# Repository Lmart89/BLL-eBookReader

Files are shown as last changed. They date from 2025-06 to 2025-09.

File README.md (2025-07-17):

# 📘 Bll Pilot

**Bll Pilot** es un proyecto de hardware libre y software de código abierto cuyo propósito es crear un lector de eBooks bíblicos de bajo consumo, enfocado en la simplicidad, portabilidad y larga duración de batería, diseñado especialmente para funcionar en zonas de baja conectividad o para uso personal/devocional.

> ✝️ *“Bll” representa muchas cosas: por un lado, “Biblia de Lectura Libre”, como un enfoque hacia el acceso abierto a la Palabra. Pero también son las iniciales de tres personas que inspiran profundamente este proyecto: Brillyd (esposa), Lemuel (hijo) y Luis (autor). "Pilot" señala que esta es la primera etapa o base para versiones futuras.*

---

## 🚀 Estado del proyecto

✨ **Actualización clave:** Al adoptar el módulo Core 3506B, el proyecto gana notables ventajas:

- 🧠 Procesador Quad-Core para mejor rendimiento multitarea
- 🎨 GPU integrada que mejora la fluidez gráfica incluso en pantallas E-Ink
- 🚀 Duplicación de RAM: de 256MB (anteriormente) a 512MB DDR3L
- 🔌 Mayor cantidad de pines IO (120), facilitando expansión sin conflictos

Estas mejoras colocan al *Bll Pilot* en una posición robusta para futuras funcionalidades sin sacrificar simplicidad ni eficiencia.

🔧 En desarrollo activo – Actualmente se encuentra en fase de diseño de hardware y primeros prototipos físicos.

La primera versión se centrará en:
- Lectura offline de textos bíblicos
- Bajo consumo y pantalla de tinta electrónica
- Interfaz minimalista para navegación fluida

---

## 🔩 Características técnicas

### 🧠 Módulo principal

- **Módulo base:** `Luckfox Core 3506B`
- **Chip:** Rockchip RK3506B
- **Procesador:** 3× Cortex-A7 + 1× Cortex-M0
- **RAM:** 512 MB DDR3L externa
- **Almacenamiento:** eMMC 8 GB por defecto
- **Almacenamiento soportado:** SPI Flash / eMMC / SDMMC
- **RM_IO:** 32 pines Rockchip Matrix IO
- **GPU:** Aceleración 2D/3D integrada
- **Conectividad:** USB host, soporte para Wi-Fi vía dongle USB (o versión Lyra W con Wi-Fi onboard)
- **Dimensiones:** 32 mm × 32 mm
- **Conectores:** 120 pines tipo *stamp hole*

### 🖥️ Pantalla
- Tipo: Pantalla E-Ink ED060XD4 (6 pulgadas, reciclada de Kindle)
- Interfaz: SPI
- Controlador: Requiere PMIC externo (como TPS65185)

### 🔌 Conectividad
- Táctil capacitivo (opcional, vía I2C)
- MicroSD (opcional)
- USB tipo C para carga y datos

### 🔋 Energía
- Batería de polímero de litio (con circuito de protección y carga)
- Circuito de bajo consumo en standby

---

## 📱 Software

El sistema estará basado en:
- 🐧 **Linux embebido** con Buildroot
- 🧱 Interfaz ligera (basada en LVGL o framebuffer directo)
- 📖 Motor de renderizado de textos optimizado para pantallas E-Ink
- 🕮 Indexación de la Biblia en diferentes versiones
- ⛺ Posibilidad de agregar documentos EPUB, TXT o formatos ligeros

---

## 🔓 Licencia

### 🔧 Hardware
Este proyecto está licenciado bajo la **CERN Open Hardware License v2 – Strongly Reciprocal (CERN OHL v2-S)**.

> Esto significa que cualquier derivado del hardware deberá mantenerse igualmente abierto y compartido con la comunidad.

### 💾 Software
El software se publica bajo la **GNU General Public License v3.0 (GPLv3)**.

> Esta licencia protege las libertades de uso, estudio, modificación y distribución del código, asegurando que permanezca siempre libre para todos los usuarios.

---

## 🧭 Visión futura

**Bll Pilot** nace como una plataforma que va más allá de ser un lector de eBooks:

- 📖 Herramienta de estudio bíblico portátil
- ⛺ Recurso para comunidades en zonas rurales o de difícil acceso
- 🛠️ Plataforma educativa para makers que deseen aprender sobre hardware embebido
- 📚 Dispositivo de lectura privada o devocional

Más adelante podrían desarrollarse versiones ampliadas, con audio, conectividad Wi-Fi permanente, y sincronización de notas o planes de lectura.

---

## 🙏 Créditos y agradecimientos

Proyecto impulsado por Luis E. Martínez S., con pasión por la electrónica, la Biblia, y el aprendizaje autodidacta.

Inspirado en la necesidad de crear herramientas útiles, abiertas y accesibles para todos.

> *Soli Deo Gloria.*

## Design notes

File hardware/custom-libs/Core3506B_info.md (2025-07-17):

# 📦 Información técnica del módulo Luckfox Core 3506B

El **Luckfox Core 3506B** es un módulo de cómputo compacto basado en el chip **Rockchip RK3506B**, diseñado para aplicaciones embebidas que requieren buen rendimiento, eficiencia energética y flexibilidad de expansión. Es ideal para dispositivos portátiles como el lector *Bll Pilot*.

---

## 🔍 Especificaciones generales

| Campo | Descripción |
|---|---|
| **SoC** | Rockchip RK3506B |
| **CPU** | 3× ARM Cortex-A7 (hasta 1.5 GHz) + 1× Cortex-M0 |
| **GPU** | Integrada, soporte para gráficos 2D y 3D |
| **RAM** | 512 MB DDR3L externa |
| **Almacenamiento** | eMMC 8 GB integrada |
| **Soporte adicional** | SPI Flash, SDMMC (microSD) |
| **Pines RM_IO** | 32 líneas Rockchip Matrix IO |
| **Pines totales** | 120 pines tipo *stamp hole* (espaciado 2.54 mm) |
| **Interfaces disponibles**| SPI, I2C, UART, PWM, USB, GPIO, SDIO |
| **Dimensiones** | 32 mm × 32 mm |
| **Consumo energético** | Bajo (ideal para dispositivos portátiles) |
| **Conectividad** | USB Host, posibilidad de WiFi vía dongle USB<br>Versiones Lyra W integran WiFi onboard |

---

## ✅ Ventajas clave

- 🧠 **Rendimiento superior:** arquitectura de 4 núcleos (3 Cortex-A7 + 1 Cortex-M0)
- 🎨 **Aceleración gráfica:** GPU integrada con soporte para 2D/3D
- 🔄 **Matrix IO:** multiplexación flexible de 32 líneas IO
- 🔧 **Diseño compacto:** ideal para placas base personalizadas
- 🔌 **Expansión amplia:** gracias a sus 120 pines y variedad de interfaces
- 📦 **Módulo SOM:** con formato estándar y fácil integración en diseños embebidos

---

## 📁 Aplicaciones sugeridas

- 📘 Lectores de eBooks (como *Bll Pilot*)
- 🏭 Interfaces industriales simples
- 📟 Terminales embebidos con pantalla de bajo consumo
- 🌐 Dispositivos conectados con WiFi externo o controladores USB
- 🎓 Plataformas educativas y proyectos maker

---

## 📎 Notas adicionales

- El módulo requiere una placa base (carrier board) que lo alimente y exponga sus periféricos.
- No incluye Wi-Fi de fábrica en esta versión (Core 3506B), pero puede añadirse vía dongle USB o mediante el uso del modelo **Lyra W**.

---

> Para más detalles técnicos, puedes visitar: https://wiki.luckfox.com/Core3506/Introduction (sitio oficial del fabricante)

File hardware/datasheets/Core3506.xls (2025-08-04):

PIN | NAME | GPIO | RMIO | 0800 Domain | 0808 Domain | PINMUX
1 | GPO4_A4_z | 132 |  | 1.8V | 1.8V | MIPI_DPHY_DSI_TX_CLKN
2 | GPO4_A5_z | 133 |  | 1.8V | 1.8V | MIPI_DPHY_DSI_TX_CLKP
3 | GND
4 | GPO4_A2_z | 130 |  | 1.8V | 1.8V | MIPI_DPHY_DSI_TX_D1N
5 | GPO4_A3_z | 131 |  | 1.8V | 1.8V | MIPI_DPHY_DSI_TX_D1P
6 | GND
7 | GPO4_A0_z | 128 |  | 1.8V | 1.8V | MIPI_DPHY_DSI_TX_D0N
8 | GPO4_A1_z | 129 |  | 1.8V | 1.8V | MIPI_DPHY_DSI_TX_D0P
9 | GND
10 | GPIO2_C0_d | 80 |  | 3.3V | 3.3V | ETH_RMII0_RXDVCRS/SAI3_MCLK
11 | GPIO2_B7_d | 79 |  | 3.3V | 3.3V | ETH_RMII0_MDIO/DSM_AUD_LP_M1/SAI3_SDO
12 | GPIO2_B6_d | 78 |  | 3.3V | 3.3V | ETH_RMII0_MDC/DSM_AUD_LN_M1/SAI3_SDI
13 | GPIO2_B5_d | 77 |  | 3.3V | 3.3V | ETH_RMII0_TXEN/DSM_AUD_RP_M1/SAI3_LRCK
14 | GPIO2_B4_d | 76 |  | 3.3V | 3.3V | ETH_RMII0_TXD1/DSM_AUD_RN_M1/SAI3_SCLK
15 | GPIO2_B3_d | 75 |  | 3.3V | 3.3V | ETH_RMII0_TXD0/SPI2_MISO
16 | GPIO2_B2_d | 74 |  | 3.3V | 3.3V | ETH_RMII0_CLK/SPI2_MOSI
17 | GPIO2_B1_d | 73 |  | 3.3V | 3.3V | ETH_RMII0_RXD1/SPI2_CSN
18 | GPIO2_B0_d | 72 |  | 3.3V | 3.3V | ETH_RMII0_RXD0/SPI2_CLK
19 | GND
20 | GPIO2_A0_d | 64 |  | 3.3V | 3.3V | FSPI_CSN
21 | GPIO2_A1_d | 65 |  | 3.3V | 3.3V | FSPI_CLK
22 | GPIO2_A2_d | 66 |  | 3.3V | 3.3V | FSPI_D0
23 | GPIO2_A3_d | 67 |  | 3.3V | 3.3V | FSPI_D1
24 | GPIO2_A4_d | 68 |  | 3.3V | 3.3V | FSPI_D2
25 | GPIO2_A5_d | 69 |  | 3.3V | 3.3V | FSPI_D3
26 | GND
27 | GPIO1_D3_d | 59 | RM_IO31 | 3.3V | 3.3V | VO_LCDC_D0/DSMC_CSN3/FLEXBUS0_D0/UART5_RX_M1/RM_IO31/DSMC_SLV_RDYN
28 | GPIO1_D2_d | 58 | RM_IO30 | 3.3V | 3.3V | VO_LCDC_D1/DSMC_CSN2/FLEXBUS0_D1/UART5_TX_M1/RM_IO30/DSMC_SLV_CSN0
29 | GPIO1_D1_d | 57 | RM_IO29 | 3.3V | 3.3V | VO_LCDC_D2/DSMC_DQS1/FLEXBUS0_D2/DSM_AUD_LP_M0/UART5_RTSN_M1/RM_IO29/DSMC_SLV_D7
30 | GPIO1_D0_d | 56 |  | 3.3V | 3.3V | VO_LCDC_D3/DSMC_D15/FLEXBUS0_D3/DSM_AUD_LN_M0/DSMC_SLV_D6
31 | GPIO1_C7_d | 55 |  | 3.3V | 3.3V | VO_LCDC_D4/DSMC_D14/FLEXBUS0_D4/DSMC_SLV_D5
32 | GPIO1_C6_d | 54 |  | 3.3V | 3.3V | VO_LCDC_D5/DSMC_D13/FLEXBUS0_D5/DSMC_SLV_D4
33 | GPIO1_C5_d | 53 |  | 3.3V | 3.3V | VO_LCDC_D6/DSMC_D12/FLEXBUS0_D6/DSMC_SLV_D3
34 | GPIO1_C4_d | 52 |  | 3.3V | 3.3V | VO_LCDC_D7/DSMC_D11/FLEXBUS0_D7/DSMC_SLV_D2
35 | GPIO1_C3_d | 51 | RM_IO28 | 3.3V | 3.3V | VO_LCDC_D8/DSMC_D10/FLEXBUS0_D8/FLEXBUS1_CSN_M5/SAI2_SDO_M1/RM_IO28/DSMC_SLV_D1
36 | GPIO1_C2_d | 50 | RM_IO27 | 3.3V | 3.3V | VO_LCDC_D9/DSMC_D9/FLEXBUS0_D9/DSM_AUD_RP_M0/FLEXBUS0_CSN_M5/SAI2_SDI_M1/RM_IO27/DSMC_SLV_D0
37 | GPIO1_C1_d | 49 |  | 3.3V | 3.3V | VO_LCDC_D10/DSMC_D8/FLEXBUS0_CLK/DSM_AUD_RN_M0/FLEXBUS1_CSN_M4/SAI2_MCLK_M1/DSMC_SLV_DQS0
38 | GPIO1_C0_d | 48 |  | 3.3V | 3.3V | VO_LCDC_D11/DSMC_RESETN/FLEXBUS1_CLK/DSMC_INT1/FLEXBUS0_CSN_M4/DSMC_SLV_CLK
39 | GPIO1_B7_d | 47 |  | 3.3V | 3.3V | VO_LCDC_D12/DSMC_RDYN/FLEXBUS1_D15/FLEXBUS0_D10/FLEXBUS1_CSN_M3
40 | GPIO1_B6_d | 46 |  | 3.3V | 3.3V | VO_LCDC_D13/DSMC_CSN0/FLEXBUS1_D14/FLEXBUS0_D11/FLEXBUS0_CSN_M3
41 | GPIO1_B5_d | 45 |  | 3.3V | 3.3V | VO_LCDC_D14/DSMC_D7/FLEXBUS1_D13/FLEXBUS0_D12/FLEXBUS1_CSN_M2
42 | GPIO1_B4_d | 44 |  | 3.3V | 3.3V | VO_LCDC_D15/DSMC_D6/FLEXBUS1_D12/FLEXBUS0_D13/FLEXBUS0_CSN_M2
43 | GPIO1_B3_d | 43 | RM_IO26 | 3.3V | 3.3V | VO_LCDC_D16/DSMC_INT3/FLEXBUS1_D11/FLEXBUS0_D14/FLEXBUS1_CSN_M1/SAI2_LRCK_M1/RM_IO26
44 | GPIO1_B2_d | 42 | RM_IO25 | 3.3V | 3.3V | VO_LCDC_D17/DSMC_INT2/FLEXBUS1_D10/FLEXBUS0_D15/FLEXBUS0_CSN_M1/SAI2_SCLK_M1/RM_IO25
45 | GPIO1_B1_d | 41 | RM_IO24 | 3.3V | 3.3V | VO_LCDC_D18/DSMC_CSN1/FLEXBUS1_D9/FLEXBUS1_CSN_M0/UART5_CTSN_M1/RM_IO24
46 | GPIO1_B0_d | 40 |  |  |  | VO_LCDC_D19/DSMC_D5/FLEXBUS1_D8/FLEXBUS0_CSN_M0
47 | GND
48 | GPIO1_A7_d | 39 |  | 3.3V | 3.3V | VO_LCDC_D20/DSMC_D4/FLEXBUS1_D7
49 | GPIO1_A6_d | 38 |  | 3.3V | 3.3V | VO_LCDC_D21/DSMC_D3/FLEXBUS1_D6
50 | GPIO1_A5_d | 37 |  | 3.3V | 3.3V | VO_LCDC_D22/DSMC_D2/FLEXBUS1_D5
51 | GPIO1_A4_d | 36 |  | 3.3V | 3.3V | VO_LCDC_D23/DSMC_D1/FLEXBUS1_D4
52 | GPIO1_A3_d | 35 |  | 3.3V | 3.3V | VO_LCDC_CLK/DSMC_D0/FLEXBUS1_D3
53 | GPIO1_A2_d | 34 |  | 3.3V | 3.3V | VO_LCDC_HSYNC/DSMC_DQS0/FLEXBUS1_D2
54 | GPIO1_A1_d | 33 |  | 3.3V | 3.3V | VO_LCDC_VSYNC/DSMC_CLKN/FLEXBUS1_D1/DSMC_INT0/DSMC_SLV_INT
55 | GPIO1_A0_d | 32 |  | 3.3V | 3.3V | VO_LCDC_DEN/DSMC_CLKP/FLEXBUS1_D0
56 | GPIO0_C7_u | 23 | RMIO_23 | 3.3V | 3.3V | UART0_RX/JTAG_TMS_M1/RM_IO23
57 | GPIO0_C6_u | 22 | RMIO_22 | 3.3V | 3.3V | UART0_TX/JTAG_TCK_M1/RM_IO22
58 | GPIO0_C4_d | 20 | RMIO_20 | 3.3V | 3.3V | ETH_CLK0_25M_OUT/AUPLL_CLK_IN/RM_IO20
59 | GPIO0_C3_d | 19 | RMIO_19 | 3.3V | 3.3V | ETH_CLK1_25M_OUT/SPI0_CSN0/RM_IO19
60 | GPIO0_C2_d | 18 | RMIO_18 | 3.3V | 3.3V | REF_CLK1_OUT/SPI0_MISO/RM_IO18
61 | GPIO0_C1_d | 17 | RMIO_17 | 3.3V | 3.3V | SPI0_MOSI/RM_IO17
62 | GPIO0_C0_d | 16 | RMIO_16 | 3.3V | 3.3V | SPI0_CLK/RM_IO16
63 | GPIO0_B7_d | 15 | RMIO_15 | 3.3V | 3.3V | SAI1_SDO3/SPI0_CSN1/RM_IO15
64 | GPIO0_B6_d | 14 | RMIO_14 | 3.3V | 3.3V | SAI1_SDO2/SPI1_CSN0/RM_IO14
65 | GPIO0_B5_d | 13 | RMIO_13 | 3.3V | 3.3V | SAI1_SDO1/RM_IO13
66 | GPIO0_B4_d | 12 | RMIO_12 | 3.3V | 3.3V | SAI1_SDO0/RM_IO12
67 | GPIO0_B3_d | 11 | RMIO_11 | 3.3V | 3.3V | SAI1_SDI/RM_IO11
68 | GPIO0_B2_d | 10 | RMIO_10 | 3.3V | 3.3V | SAI1_LRCK/SPI1_MISO/RM_IO10
69 | GPIO0_B1_d | 9 | RMIO_9 | 3.3V | 3.3V | SAI1_SCLK/SPI1_MOSI/RM_IO9
70 | GPIO0_B0_d | 8 | RMIO_8 | 3.3V | 3.3V | SAI1_MCLK/SPI1_CLK/RM_IO8
71 | GND
72 | GPIO0_A7_d | 7 | RMIO_7 | 3.3V | 3.3V | SAI0_SDI3/SPI1_CSN1/RM_IO7
73 | GPIO0_A6_d | 6 | RMIO_6 | 3.3V | 3.3V | SAI0_SDI2/RM_IO6
74 | GPIO0_A5_d | 5 | RMIO_5 | 3.3V | 3.3V | SAI0_SDI1/RM_IO5
75 | GPIO0_A4_d | 4 | RMIO_4 | 3.3V | 3.3V | SAI0_SDI0/RM_IO4
76 | GPIO0_A3_d | 3 | RMIO_3 | 3.3V | 3.3V | SAI0_SDO/RM_IO3
77 | GPIO0_A2_u | 2 | RMIO_2 | 3.3V | 3.3V | SAI0_MCLK/RM_IO2
78 | GPIO0_A1_d | 1 | RMIO_1 | 3.3V | 3.3V | SAI0_SCLK/RM_IO1
79 | GPIO0_A0_u | 0 | RMIO_0 | 3.3V | 3.3V | SAI0_LRCK/RM_IO0
80 | NPOR_L |  |  | 3.3V | 3.3V
81 | GND
82 | GPIO0_D0_d | 24 |  | 3.3V | 3.3V | OSC_CLK_OUT/REF_CLK0_OUT
83 | VCC_1V8
84 | VCC_3V3
85 | VCC5V0_SYS
86 | VCC5V0_SYS
87 | VCC5V0_SYS
88 | GND
89 | GND
90 | GND
91 | GPIO3_B6_d | 110 |  | 3.3V | 1.8V | SAI2_MCLK_M0/ETH_RMII1_RXDVCRS
92 | GPIO3_B5_d | 109 |  | 3.3V | 1.8V | UART5_RTSN_M0/ETH_RMII1_MDIO
93 | GPIO3_B4_d | 108 |  | 3.3V | 1.8V | UART5_TX_M0/ETH_RMII1_MDC
94 | GPIO3_B3_d | 107 |  | 3.3V | 1.8V | UART5_RX_M0/ETH_RMII1_TXEN
95 | GPIO3_B2_d | 106 |  | 3.3V | 1.8V | UART5_CTSN_M0/ETH_RMII1_TXD1
96 | GPIO3_B1_d | 105 |  | 3.3V | 1.8V | SAI2_LRCK_M0/ETH_RMII1_TXD0
97 | GPIO3_B0_d | 104 |  | 3.3V | 1.8V | SAI2_SDO_M0/ETH_RMII1_CLK
98 | GPIO3_A7_d | 103 |  | 3.3V | 1.8V | SAI2_SCLK_M0/ETH_RMII1_RXD1
99 | GPIO3_A6_d | 102 |  | 3.3V | 1.8V | SAI2_SDI_M0/ETH_RMII1_RXD0
100 | GND
101 | GPIO3_A5_d | 101 |  | 3.3V | 1.8V(NC) | SDMMC_D3/JTAG_TMS_M0
102 | GPIO3_A4_d | 100 |  | 3.3V | 1.8V(NC) | SDMMC_D2/JTAG_TCK_M0
103 | GPIO3_A3_d | 99 |  | 3.3V | 1.8V(NC) | SDMMC_D1/TEST_CLK_OUT
104 | GPIO3_A2_d | 98 |  | 3.3V | 1.8V(NC) | SDMMC_D0
105 | GPIO3_A1_d | 97 |  | 3.3V | 1.8V(NC) | SDMMC_CMD
106 | GPIO3_A0_d | 96 |  | 3.3V | 1.8V(NC) | SDMMC_CLK
107 | GND
108 | USB20_OTG0_D_P
109 | USB20_OTG0_D_N
110 | USB20_OTG1_D_P
111 | USB20_OTG1_D_N
112 | USB20_OTG0_ID
113 | USB20_OTG0_VBUSDET
114 | GPIO4_B0_z | 136 |  | 1.8V | 1.8V | SARADC_IN0
115 | GPIO4_B1_z | 137 |  | 1.8V | 1.8V | SARADC_IN1
116 | GPIO4_B2_z | 138 |  | 1.8V | 1.8V | SARADC_IN2
117 | GPIO4_B3_z | 139 |  | 1.8V | 1.8V | SARADC_IN3
118 | GND
119 | ACODEC_ADC_IN_P |  |  | 1.8V | 1.8V
120 | ACODEC_ADC_IN_N |  |  | 1.8V | 1.8V

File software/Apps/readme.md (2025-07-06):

# 📖 eBook Reader - Apps y Módulos

Este documento describe las **aplicaciones** que forman parte del eBook Reader, los lenguajes utilizados, sus dependencias, cómo integrarlas al sistema y ejemplos prácticos de desarrollo.

---

## 🛠 Lenguajes y frameworks

Las aplicaciones del eBook Reader están desarrolladas principalmente en:

| Componente | Lenguaje | Framework |
|---|---|---|
| Interfaz gráfica | C / C++  | LVGL (Light and Versatile Graphics Library) |
| Lógica / Backend | C / C++  | Nativo, sin frameworks pesados |
| Scripts utilitarios | Python (opcional, durante generación de datos, no en runtime) | - |

El uso de C/C++ permite máxima eficiencia en el hardware limitado (RV1106, 256 MB RAM).

### ⚙ Herramientas de compilación sugeridas

- **Makefiles** o **CMake** para proyectos C/C++.
- Toolchain generada por Buildroot (cross-compilador para RV1106).
- LVGL como librería estática incluida en el build.

---

## 📦 Aplicaciones principales

| App | Descripción | Binario / Módulo | Dependencias |
|---|---|---|---|
| **BibleTool** | Lectura, búsqueda y estudio bíblico | Binario integrado  | LVGL, acceso a CSV/JSON |
| **BookReader**| Lector de libros electrónicos | Binario integrado  | LVGL |
| **NoteApp** | App de notas y apuntes | Módulo o binario | LVGL |
| **Settings**  | Configuración del sistema | Módulo esencial | LVGL |

---

## 🔗 Integración al eBook Reader

- **Formato**: Las apps se integran como binarios independientes o módulos que el sistema llama desde el menú principal.
- **Compilación**: Cada app debe ser compilada estáticamente o como binario cargable desde el almacenamiento.
- **Recursos compartidos**: Framebuffer, entrada táctil (si disponible), eMMC, red.
- **Datos**: Formatos planos (CSV, JSON) alojados en el eMMC.

### 📂 Ejemplo de estructura de proyecto

```
/apps
  /bibletool
    main.c
    Makefile
    lv_conf.h
    /assets
      logo.bin
    /data
      rv60.csv
      diccionario.json
```

### 📝 Ejemplo de Makefile

```makefile
CC = arm-linux-gnueabihf-gcc
CFLAGS = -O2 -static
LDFLAGS = -llvgl

TARGET = bibletool
SRCS = main.c

all:
\t$(CC) $(CFLAGS) -o $(TARGET) $(SRCS) $(LDFLAGS)

clean:
\trm -f $(TARGET)
```

### 🚀 Comando de compilación

```bash
make
```
o manualmente:
```bash
arm-linux-gnueabihf-gcc -O2 -static -o bibletool main.c -llvgl
```

### 🛠 Instrucciones para integrar el binario

1️⃣ Copia el binario al dispositivo:
```bash
scp bibletool root@device:/apps/bibletool
```

2️⃣ Asegura permisos de ejecución:
```bash
chmod +x /apps/bibletool
```

3️⃣ Edita el menú del launcher:
```bash
vi /etc/ebook_launcher.conf
```
Y añade:
```
BibleTool,/apps/bibletool
```

---

## ✅ Requerimientos para añadir nuevas apps

- C/C++ o compatible con el entorno minimalista.
- Uso de LVGL o interfaz directa sobre framebuffer.
- Binarios compactos (ideal < 2 MB).
- Sin librerías externas pesadas.
- Integración al menú mediante launcher.

---

## 📄 Licencia

Las aplicaciones están licenciadas bajo **GPLv3**, salvo indicación diferente en casos particulares.

---

Si deseas más detalles sobre la creación de nuevas aplicaciones o la arquitectura de integración, revisa la documentación de **Buildroot** y **LVGL**.

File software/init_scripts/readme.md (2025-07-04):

# Scripts

Aqui se encuentran los scripts de configuracion del sistema buildroot. 
y cualquier otro script de configuracion o inicializacion de alguno de los componentes
o configuracion del software o scripts de inicializacion de paquetes personalizados.

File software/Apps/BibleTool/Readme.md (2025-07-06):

# BibleTool

**BibleTool** es una aplicación ligera, eficiente y de bajo consumo diseñada para el estudio y la consulta de la Biblia en dispositivos de recursos limitados, como e-readers basados en Linux con Buildroot (por ejemplo: el eReader personalizado de este proyecto).

BibleTool se construye con el objetivo de ofrecer una experiencia de estudio bíblico fluida, práctica y personalizable, sin sacrificar velocidad ni simplicidad.

---

## ¿Qué es BibleTool?

BibleTool es un motor de lectura y búsqueda bíblica que:

- Permite consultar el texto completo de la Biblia en español (Reina-Valera 1960 o 1909).
- Realiza búsquedas rápidas de palabras o frases en toda la Biblia, por testamento o por tipo de libro (ley, histórico, poético, profético, evangelio, epístola, apocalíptico).
- Muestra comentarios asociados a versículos específicos.
- Permite consultar definiciones y conceptos mediante un diccionario bíblico integrado.
- Diseñado para una interfaz basada en **LVGL** (Light and Versatile Graphics Library) y código en **C/C++**.

---

## Funcionalidades principales

✅ **Consulta de versículos**\
✅ **Búsqueda avanzada por palabra clave** (con filtros: testamento, tipo de libro)\
✅ **Acceso a comentarios vinculados al texto bíblico**\
✅ **Consulta de diccionario bíblico**\
✅ **Soporte para módulos adicionales (comentarios, diccionarios)**\
✅ **Bajo consumo de recursos (256 MB RAM, CPU RV1106)**\
✅ **Datos optimizados en archivos CSV y JSON**

---

## Arquitectura de módulos

BibleTool está organizado en módulos que corresponden a distintos tipos de contenido:

| Módulo | Descripción | Tipo de archivo | Formato |
| --- | --- | --- | --- |
| **Biblia** | Texto completo de las Escrituras | CSV | Lb,C,V,TXT,TP,Tlb |
| **Comentarios** | Notas y comentarios por versículo o pasaje | JSON | Lista de objetos con referencia al libro, capítulo, versículo |
| **Diccionario** | Definiciones de términos bíblicos | JSON o CSV | Clave: término / Valor: definición |

### 📁 Formato de la Biblia (CSV)

| Columna | Descripción |
| --- | --- |
| Lb | Nombre del libro |
| C | Capítulo (entero positivo) |
| V | Versículo (entero positivo) |
| TXT | Texto del versículo |
| TP | Testamento: `A` = Antiguo, `N` = Nuevo |
| Tlb | Tipo de libro: `L`, `H`, `P`, `Pm`, `Pn`, `E`, `Ep`, `Ap` |

Ejemplo:

```csv
Genesis,1,1,"En el principio creó Dios los cielos y la tierra.",A,L
Mateo,1,1,"Libro de la genealogía de Jesucristo, hijo de David, hijo de Abraham.",N,E
```

---

### 📁 Formato de los comentarios (JSON)

```json
[
  {
    "Lb": "Genesis",
    "C": 1,
    "V": 1,
    "Comentario": "Dios es el creador de todo lo visible e invisible."
  },
  {
    "Lb": "Mateo",
    "C": 1,
    "V": 1,
    "Comentario": "Introducción a la genealogía de Cristo."
  }
]
```

---

### 📁 Formato del diccionario (JSON)

```json
{
  "Amor": "Sentimiento de afecto y entrega desinteresada.",
  "Fe": "Confianza y creencia en Dios y sus promesas."
}
```

*(También puede usarse CSV con dos columnas: Término, Definición)*

---

## ¿Por qué BibleTool es útil y versátil?

- 🔹 **Ligero y rápido:** Diseñado para funcionar con hardware de bajo consumo (como RV1106 + 256MB RAM).
- 🔹 **Modular:** Puedes agregar o actualizar los módulos (Biblia, comentarios, diccionarios) sin modificar el motor.
- 🔹 **Filtros de búsqueda avanzados:** Busca por testamento, tipo de libro, o combinación de ambos.
- 🔹 **Fácil de adaptar:** El formato de datos es simple, plano y bien documentado.
- 🔹 **Libre de dependencias innecesarias:** Motor hecho en C/C++ con una interfaz LVGL optimizada.

---

## Licencia

BibleTool es un proyecto abierto en desarrollo. Licencia GPLv3

---

## Créditos

BibleTool es desarrollado por **Luis E Martínez S.** como parte de un proyecto personal de eReader personalizado para estudio bíblico.

---

*Nota:* En el futuro se podrá definir un logo y otros elementos visuales para BibleTool.

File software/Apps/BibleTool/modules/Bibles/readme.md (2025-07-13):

## 📚 Progreso del Módulo de la Biblia (RV60)

Este módulo representa el corazón textual de **BibleTool**, centrado en una fuente depurada y confiable de la Biblia Reina Valera 1960 (RV60).  
A continuación se presenta el registro de validaciones y avances técnicos hasta la fecha:

---

### 🛠️ Etapas de Validación Aplicadas

| Etapa | Descripción | Estado |
|---|---|---|
| ✅ Estructura CSV definida | Archivo `rv60.csv` con columnas: `Lb`, `C`, `V`, `TXT`, `TP`, `Tlb` | Completado |
| ✅ Verificación de formato | Validación de campos no vacíos, orden y consistencia por versículo | Completado |
| ✅ Chequeo de integridad bíblica  | Revisión de libros, capítulos y versículos conforme a la RV60 | Completado |
| 🧪 Comparación textual | Comparación verso a verso contra RV1909 por conteo de palabras | En curso  |
| 🧠 Revisión semántica manual | Evaluación del significado y conservación del mensaje bíblico | En curso  |
| 🧩 Filtrado de sospechosos | Identificación de versículos con diferencias mayores al 50% | Completado |
| 🗂️ Exclusión de libros validados | Script conectado a archivo `libros_verificados.py` | Implementado |

---

### ✅ Libros Verificados (RV60 vs RV1909)

| 📖 Libro | Estado | Observación |
|---|---|---|
| Génesis | ✅ Verificado | Cambios menores de estilo sin alterar el contenido |
| Éxodo | ✅ Verificado | Diferencias lingüísticas no afectan integridad doctrinal |
| Levítico  | ⏳ En proceso | - |
| ... | | |

> Los libros verificados son excluidos automáticamente en futuras ejecuciones del comparador textual.

---

### 🧰 Herramientas de validación usadas

- `BibleChecker` – Validación de capítulos y versículos
- `comparador_rv60_rv1909.py` – Comparación textual palabra por palabra
- `libros_verificados.py` – Control automático de libros revisados
- Archivos de referencia: `SpaRV.csv` (RV1909), `rv60.csv` (RV60 final)

---

### 🔜 Próximos pasos

- 📗 Verificar Levítico y Números
- 📂 Consolidar lista de libros verificados
- ✏️ Implementar vista de lectura en LVGL
- 📦 Empaquetar recursos optimizados para el eReader

---

_Actualizado: **{{FECHA_HOY}}** por Luis E. Martínez (con asistencia de Chatty 🤖)_

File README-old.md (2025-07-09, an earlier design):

# 📖 Bll eBook Reader

**Un lector electrónico versátil, eficiente y con propósito**

---

## ✨ ¿Qué es el Bll eBook Reader?

El **Bll eBook Reader** es un lector de libros electrónicos creado desde cero, pensado no solo como una alternativa a dispositivos comerciales como el Kindle, sino como una **herramienta versátil de lectura, estudio y organización personal**, especialmente útil para quienes estudian, enseñan o predican la Biblia. Diseñado para funcionar con recursos limitados, es **libre, optimizado y altamente personalizable**.

---

## 🔧 Hardware

Este lector se basa en un hardware distinto a la mayoría de dispositivos similares, lo que permite libertad total en su desarrollo y expansión:

- **Procesador**: Luckfox Core RV1106 – Cortex-A7, eficiente y de bajo consumo.
- **RAM**: 256 MB DDR3
- **Almacenamiento**: 8 GB eMMC (integrado)
- **Pantalla**: E-Ink de 6 pulgadas (sin retroiluminación por ahora)
- **Touch**: Opcional, no habilitado en las primeras versiones
- **Conectividad**: Wi-Fi / Bluetooth integrados
- **Sistema Operativo**: Linux personalizado usando **Buildroot**
- **Placa Base**: Diseño propio (inspirado en proyectos como epdiy v7 pero adaptado al RV1106)
- **Fuente de alimentación y protección**: Incluye fusibles para proteger el SoM

---

## 🚀 Características destacadas

- 🧠 **Ultraligero**: sistema operativo minimalista con lo esencial, optimizado para bajo uso de RAM y energía.
- 📚 **Soporte para múltiples formatos de eBooks**: EPUB, MOBI, TXT, PDF (parcial).
- 📖 **Modo Biblia integrado**: navegación optimizada por libros, capítulos y versículos.
- 📝 **Notas personales**: sistema simple de notas para estudios, bosquejos y predicaciones.
- 📡 **Actualizaciones inalámbricas** (por Wi-Fi).
- 📁 **Sistema de archivos organizado** para acceder a libros, notas y documentos con rapidez.

---

## 🎯 ¿Por qué es diferente?

La mayoría de lectores electrónicos están cerrados a modificaciones. El **Bll eBook Reader** es:

- ✅ **Totalmente libre y abierto**: el software está bajo licencia GPLv3 y el hardware bajo una licencia de hardware libre.
- ✅ **Protegido contra la apropiación comercial restrictiva**: cualquier persona que modifique o redistribuya debe mantener la apertura del código y los archivos de hardware.
- ✅ **Versátil**: no se limita a libros; puede convertirse en una libreta digital, lector de notas pastorales, organizador de predicaciones, etc.
- ✅ **Diseñado para crecer**: puede extenderse con mejoras como pantalla táctil, retroiluminación o integración con servidores locales para compartir materiales.

---

## 🧱 Estado del desarrollo

- [x] Diseño del PCB personalizado
- [x] Integración básica con pantalla E-Ink
- [x] Sistema Linux embebido funcional (Buildroot)
- [ ] Interfaz gráfica liviana con **LVGL**
- [ ] Modo Biblia con navegación completa
- [ ] Sistema de notas sencillo
- [ ] Conectividad Wi-Fi funcional y segura
- [ ] Soporte para sincronización o backup

---

## 💡 Casos de uso

- Lectura diaria de la Biblia y devocionales
- Acceso a libros de estudio teológico
- Organización de bosquejos para sermones
- Anotaciones rápidas durante clases o reuniones
- Lectura offline de contenido útil sin distracciones

---

## 📜 Licencia

### Software

Este proyecto se distribuye bajo los términos de la **GNU General Public License v3.0 (GPLv3)**.  
Esto garantiza que cualquier persona que modifique o redistribuya el software **debe mantenerlo libre y accesible** bajo la misma licencia.

Consulta el archivo [`LICENSE`](./LICENSE) para más información.

### Hardware

Los archivos de hardware (esquemáticos, PCB, listas de materiales) se publican como **Open Hardware** bajo la licencia  
**CERN Open Hardware License v2 – Strongly Reciprocal**.  
Esto significa que:

- Puedes usar, estudiar, modificar y fabricar este hardware.
- Si lo redistribuyes o haces productos derivados, **debes también liberar tus archivos bajo la misma licencia**.
- **No está permitido cerrarlo ni venderlo como producto propietario** sin publicar tus modificaciones.

Consulta el archivo [`hardware/LICENSE`](./hardware/LICENSE) para más información.

---

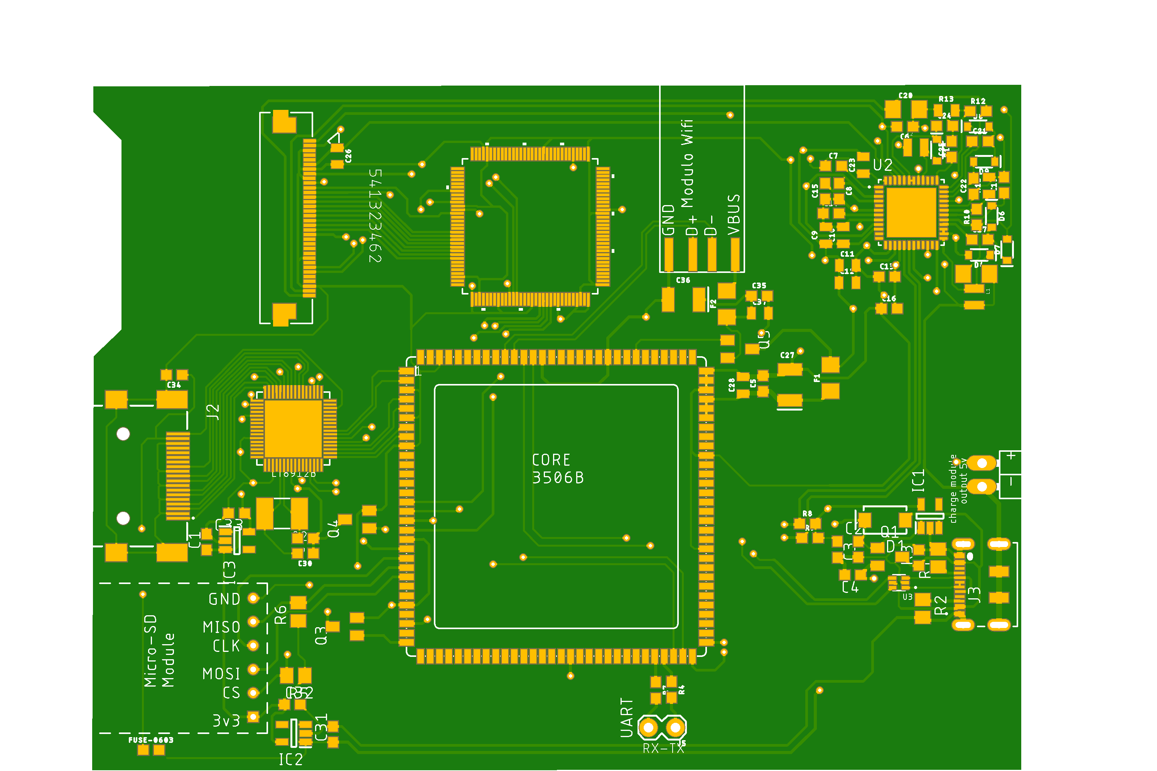
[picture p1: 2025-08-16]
hardware/sch-pcb files/BLL-EBOOK-3506-TOP.png

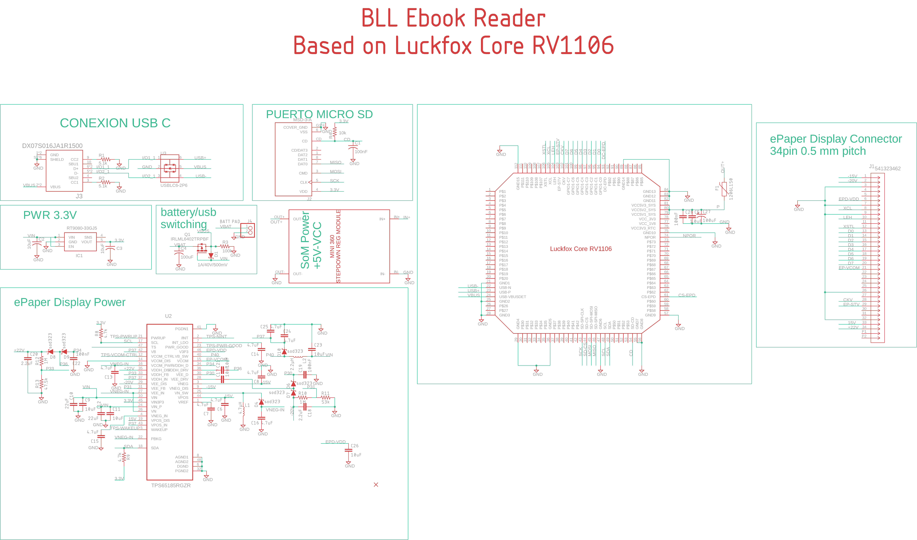
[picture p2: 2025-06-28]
hardware/sch-pcb files/SCH_V1.png

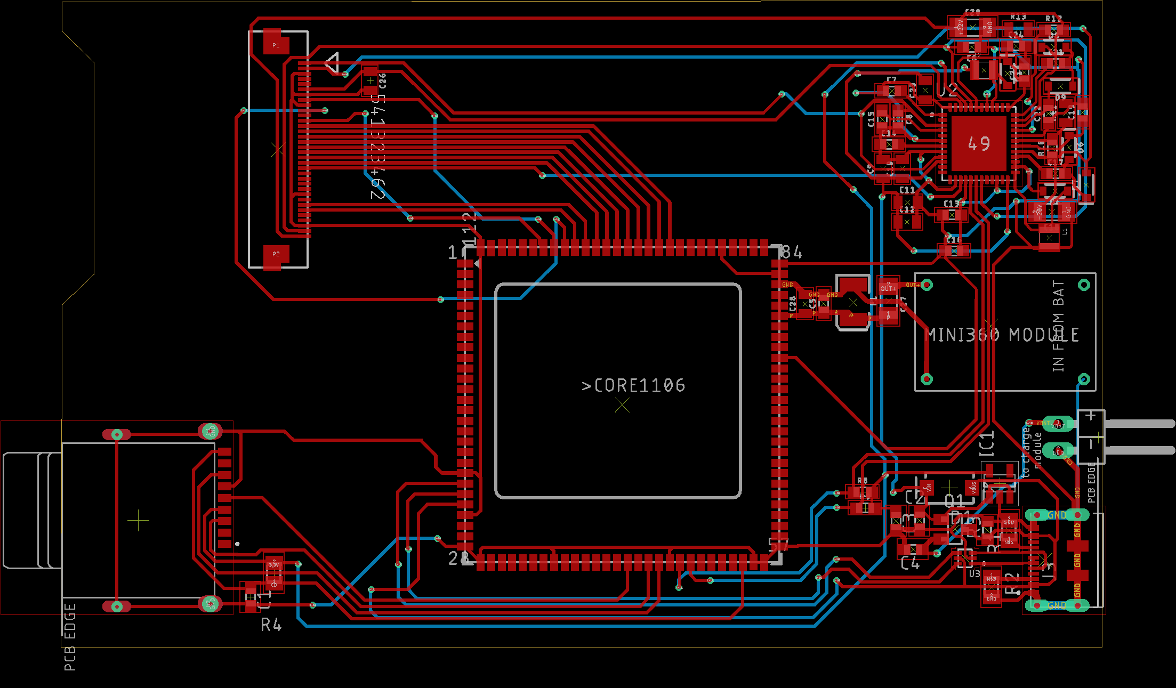
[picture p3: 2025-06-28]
hardware/sch-pcb files/PCB.png

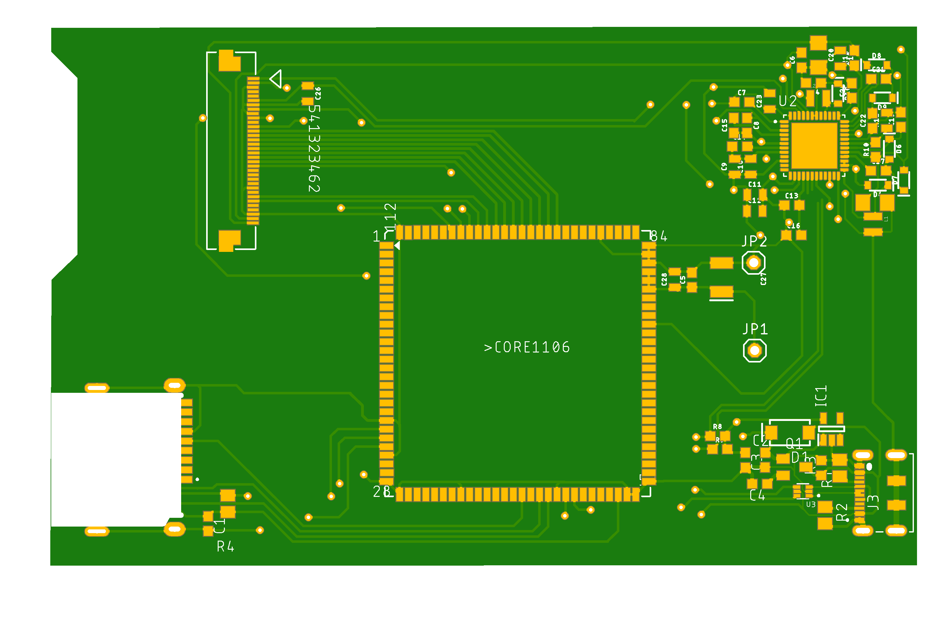
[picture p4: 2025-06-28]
docs/img/BLL-EBOOK - TOP.png

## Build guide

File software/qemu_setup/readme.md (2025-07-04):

# Qemu - Setup

esta carpeta contiene los scripts y/o opciones de configuracion de qemu para la virtualizacion, emulacion
del Buildroot en el sistema.

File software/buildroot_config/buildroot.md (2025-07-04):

# Buildroot Config

Aqui se encontrara la documentacion para la creacion de una imagen de Linux Buildroot,
y pueda ser grabada al emmc de la Bll eBook Reader.

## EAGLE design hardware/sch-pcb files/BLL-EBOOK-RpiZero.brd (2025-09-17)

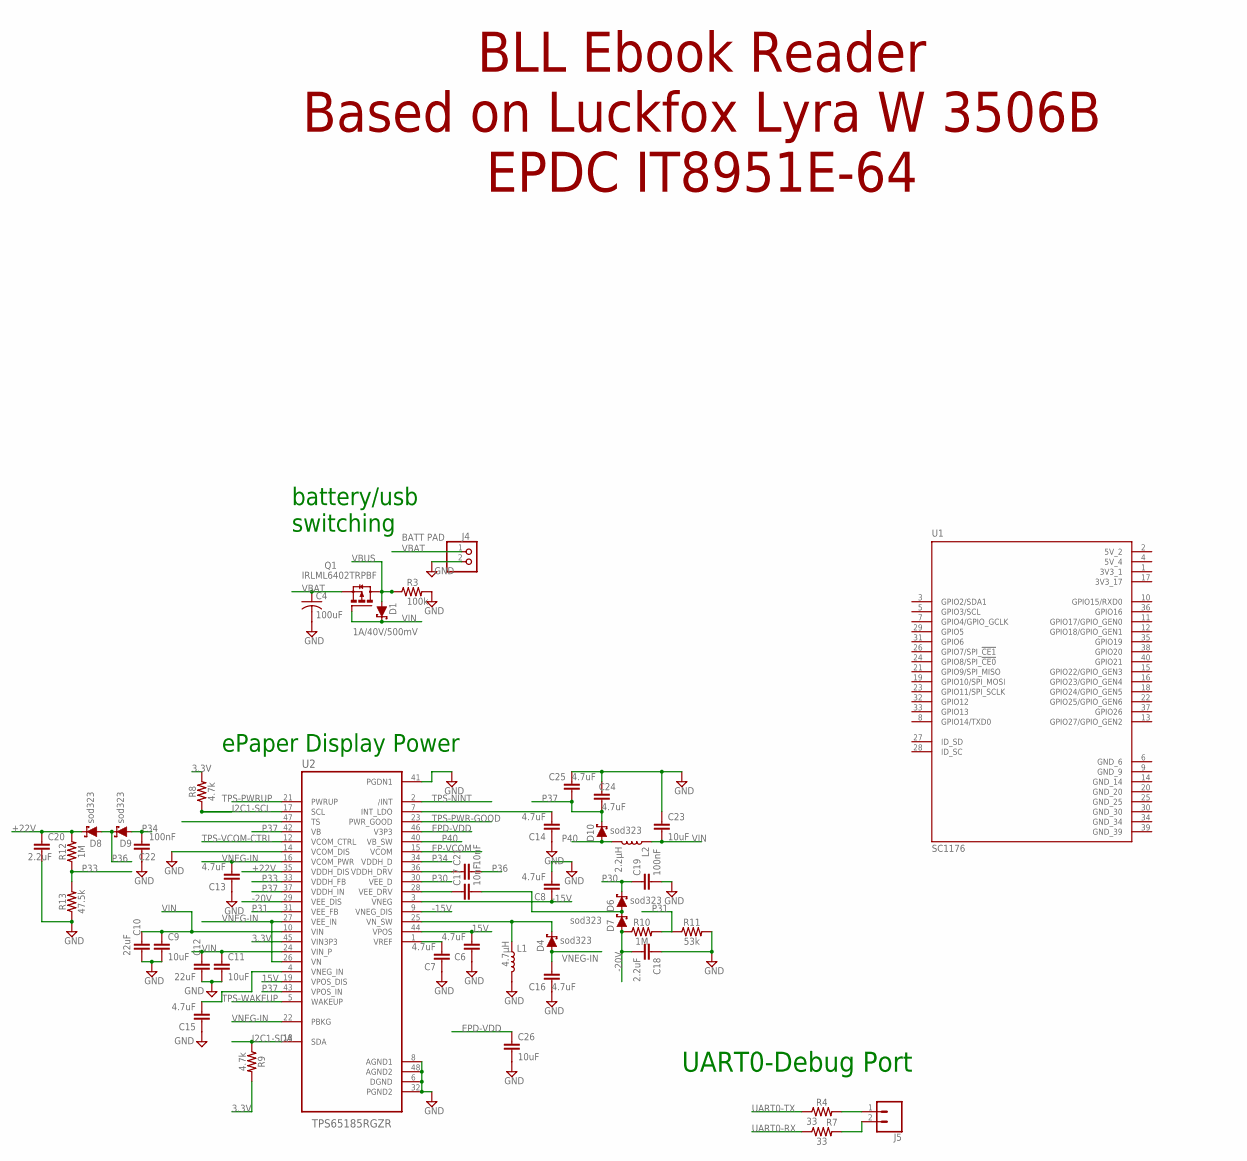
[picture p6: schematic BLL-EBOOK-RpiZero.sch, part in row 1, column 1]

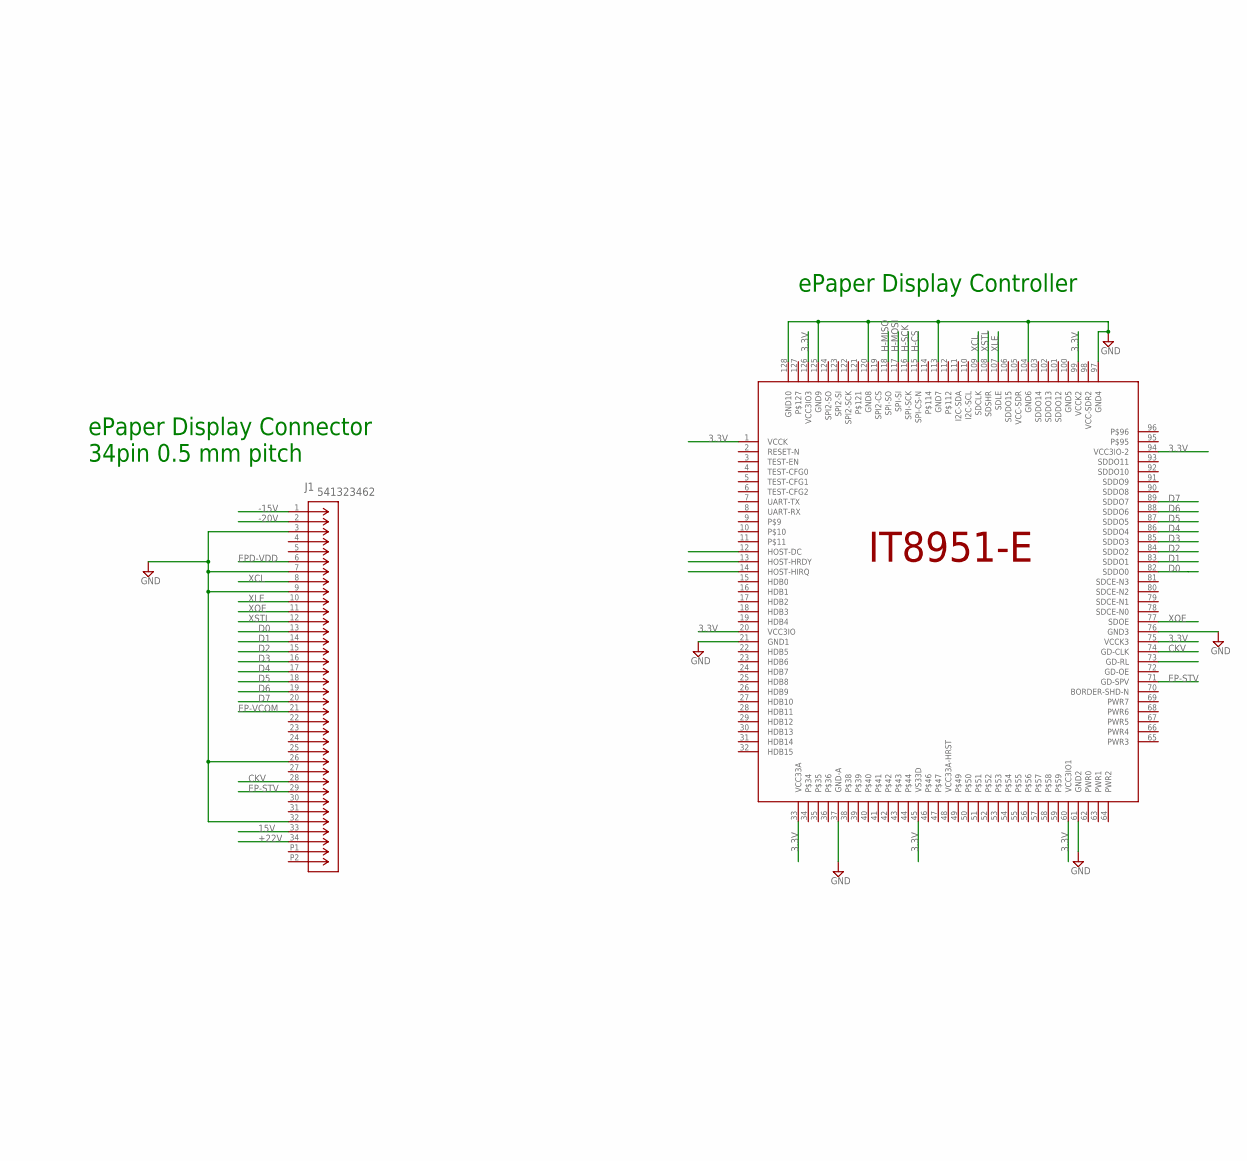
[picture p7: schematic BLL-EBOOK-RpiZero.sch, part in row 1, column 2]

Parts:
C4: 100uF; C0603
C6, C7, C8, C13, C14, C15, C16, C24, C25: 4.7uF; 0603
C9, C11, C23, C26: 10uF; 0805
C10, C12: 22uF; 0805
C17, C21: 10nF; 0603
C18, C20: 2.2uF; 1206
C19, C22: 100nF; 0603
D1: 1A/40V/500mV; SMA-DIODE
D4, D6, D7, D8, D9, D10: sod323; SOD-323
J1: 541323462; CON_541323462_MOL
J4: BATT PAD; 1X02/90
J5: CONN_02LOCK; 1X02_LOCK
L1: 4.7μH; 1008(2520)
L2: 2.2μH; 0806
Q1: IRLML6402TRPBF; SOT23
R3: 100k; R0603
R4, R7: 33; 0603
R8, R9: 4.7k; 0603
R10, R12: 1M; 0603
R11: 53k; 0805
R13: 47.5k; 0805
U1: SC1176; MODULE_SC1176
U2: TPS65185RGZR; QFN50P700X700X100-49N
U$1: IT8951; LQFP128_STM

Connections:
3.3V: R8.2, R9.2, U2.45 (VIN3P3), U$1.1 (VCCK), U$1.20 (VCC3IO), U$1.33 (VCC33A), U$1.45 (VS33D), U$1.60 (VCC3IO1), U$1.75 (VCCK3), U$1.94 (VCC3IO-2), U$1.99 (VCCK2), U$1.126 (VCC3IO3)
3V3_1: U1.1 (3V3_1)
3V3_17: U1.17 (3V3_17)
5V_2: U1.2 (5V_2)
5V_4: U1.4 (5V_4)
15V: C6.2, J1.33, U2.19 (VPOS_DIS), U2.44 (VPOS)
+22V: C20.1, D8.C, J1.34, R12.2, U2.35 (VDDH_DIS)
-15V: C8.1, J1.1, U2.3 (VNEG), U2.9 (VNEG_DIS)
-20V: C18.2, D7.A, J1.2, R10.1, U2.29 (VEE_DIS)
CKV: J1.28, U$1.74 (GD-CLK)
D0: J1.13, U$1.82 (SDDO0)
D1: J1.14, U$1.83 (SDDO1)
D2: J1.15, U$1.84 (SDDO2)
D3: J1.16, U$1.85 (SDDO3)
D4: J1.17, U$1.86 (SDDO4)
D5: J1.18, U$1.87 (SDDO5)
D6: J1.19, U$1.88 (SDDO6)
D7: J1.20, U$1.89 (SDDO7)
EP-STV: J1.29, U$1.71 (GD-SPV)
EP-VCOM: J1.21, U2.15 (VCOM)
EPD-VDD: C26.1, J1.6, U2.46 (V3P3)
GND: C4.2, C6.1, C7.1, C8.2, C9.2, C10.2, C11.2, C12.2, C13.1, C14.1, C15.1, C16.1, C18.1, C19.2, C20.2, C22.1, C23.1, C24.2, C25.2, C26.2, J1.3, J1.7, J1.9, J1.26, J1.32, J4.2, L1.2, R3.2, R11.2, R13.1, U2.6 (DGND), U2.8 (AGND1), U2.14 (VCOM_DIS), U2.32 (PGND2), U2.41 (PGDN1), U2.48 (AGND2), U$1.21 (GND1), U$1.37 (GND-A), U$1.61 (GND2), U$1.76 (GND3), U$1.97 (GND4), U$1.104 (GND6), U$1.113 (GND7), U$1.120 (GND8), U$1.125 (GND9), U$1.128 (GND10)
GND_6: U1.6 (GND_6)
GND_9: U1.9 (GND_9)
GND_14: U1.14 (GND_14)
GND_20: U1.20 (GND_20)
GND_25: U1.25 (GND_25)
GND_30: U1.30 (GND_30)
GND_34: U1.34 (GND_34)
GND_39: U1.39 (GND_39)
H-CS: U$1.115 (SPI-CS-N)
H-MISO: U$1.118 (SPI-SO)
H-MOSI: U$1.117 (SPI-SI)
H-SCK: U$1.116 (SPI-SCK)
I2C1-SCL: R8.1, U2.17 (SCL)
I2C1-SDA: R9.1, U2.18 (SDA)
unnamed: J5.1, R4.2
unnamed: J5.2, R7.2
unnamed: C7.2, U2.1 (VREF)
unnamed: C15.2, U2.4 (VNEG_IN)
unnamed: C14.2, U2.7 (INT_LDO)
unnamed: D4.C, L1.1, U2.25 (VN_SW)
unnamed: C17.1, U2.28 (VEE_DRV)
unnamed: C17.2, D6.A, D7.C
unnamed: C21.1, U2.36 (VDDH_DRV)
P30: C19.1, D6.C, U2.30 (VEE_D)
P31: R10.2, R11.1, U2.31 (VEE_FB)
P33: R12.1, R13.2, U2.33 (VDDH_FB)
P34: C22.2, D9.A, U2.34 (VDDH_D)
P36: C21.2, D8.A, D9.C
P37: C24.1, C25.1, D10.C, U2.37 (VDDH_IN), U2.42 (VB), U2.43 (VPOS_IN)
P40: D10.A, L2.2, U2.40 (VB_SW)
TPS-NINT: U2.2 (/INT)
TPS-PWR-GOOD: U2.23 (PWR_GOOD)
TPS-PWRUP: U2.21 (PWRUP)
TPS-VCOM-CTRL: U2.12 (VCOM_CTRL)
TPS-WAKEUP: U2.5 (WAKEUP)
UART0-RX: R7.1
UART0-TX: R4.1
VBAT: C4.1, J4.1, Q1.2 (S)
VBUS: D1.A, Q1.3 (D), R3.1
VIN: C9.1, C10.1, C11.1, C12.1, C23.2, D1.C, L2.1, Q1.1 (G), U2.10 (VIN), U2.24 (VIN_P)
VNEG-IN: C13.2, C16.2, D4.A, U2.16 (VCOM_PWR), U2.22 (PBKG), U2.26 (VN), U2.27 (VEE_IN)
XCL: J1.8, U$1.109 (SDCLK)
XLE: J1.10, U$1.107 (SDLE)
XOE: J1.11, U$1.77 (SDOE)
XSTL: J1.12, U$1.108 (SDSHR)

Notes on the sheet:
battery/usb switching
ePaper Display Power
ePaper Display Connector 34pin 0.5 mm pitch
BLL Ebook Reader Based on Luckfox Lyra W 3506B EPDC IT8951E-64
ePaper Display Controller
UART0-Debug Port

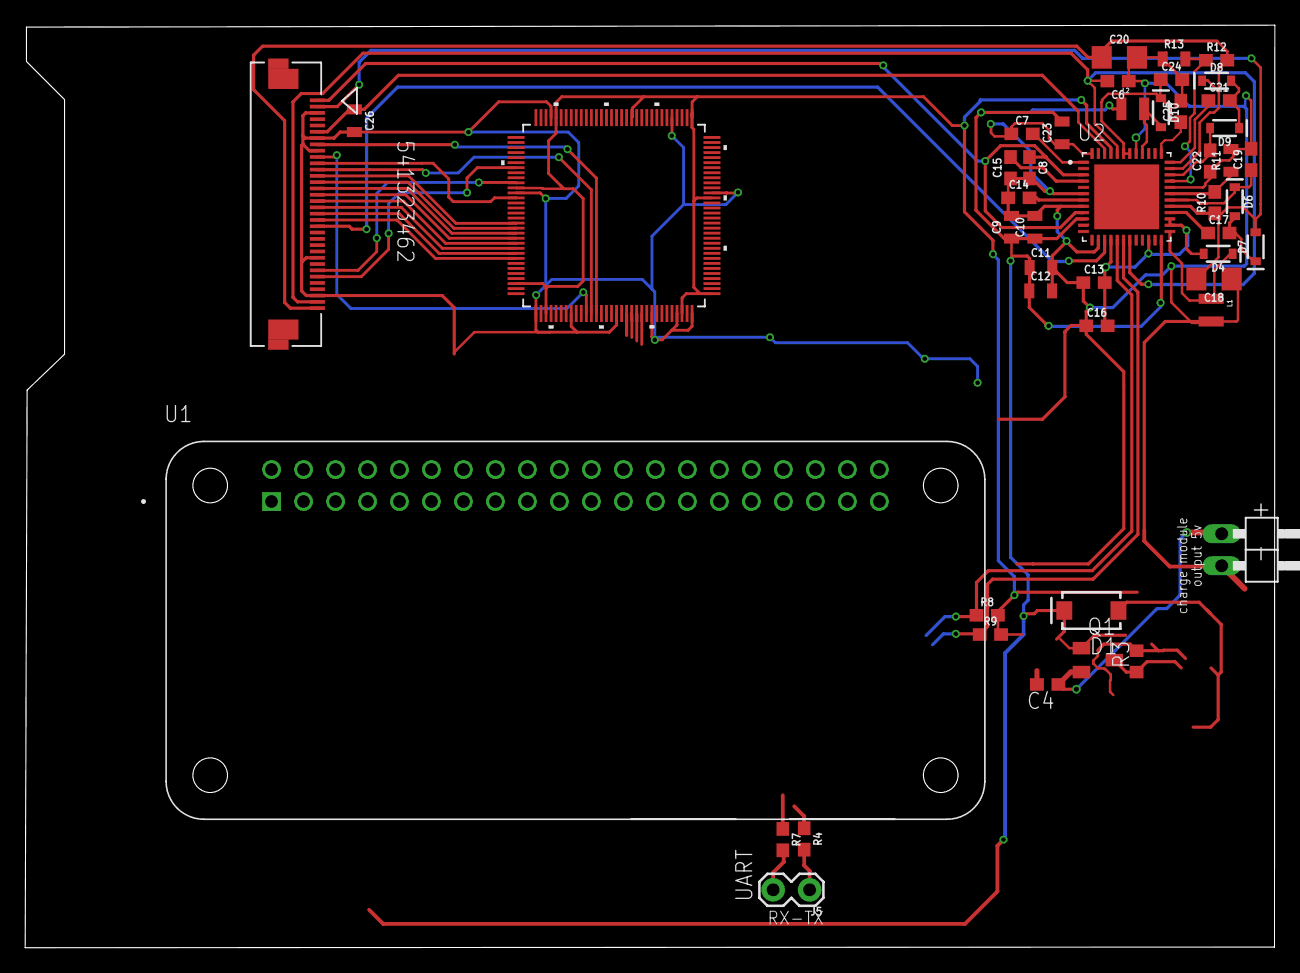
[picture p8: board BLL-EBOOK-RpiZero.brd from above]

Board: 2 copper layers, 99.2 x 73.2 mm, 47 parts (0 on the bottom side), 44 nets.

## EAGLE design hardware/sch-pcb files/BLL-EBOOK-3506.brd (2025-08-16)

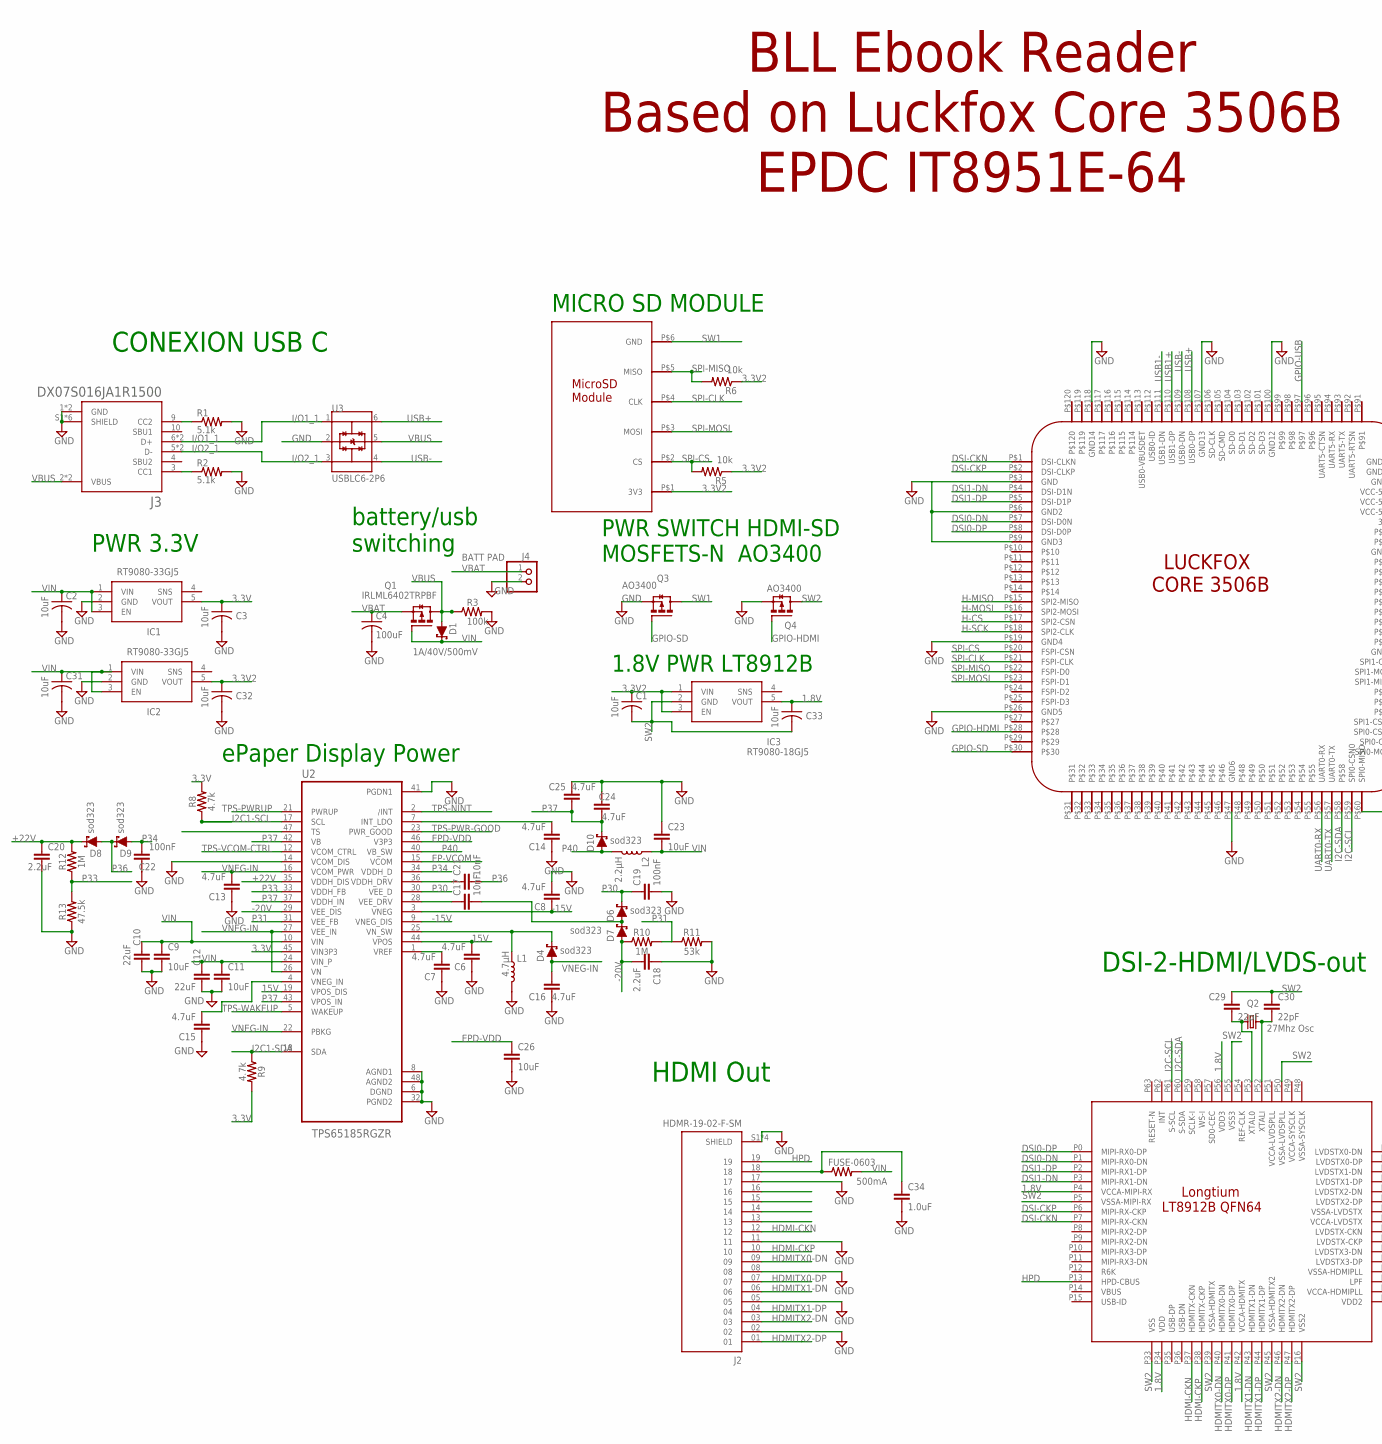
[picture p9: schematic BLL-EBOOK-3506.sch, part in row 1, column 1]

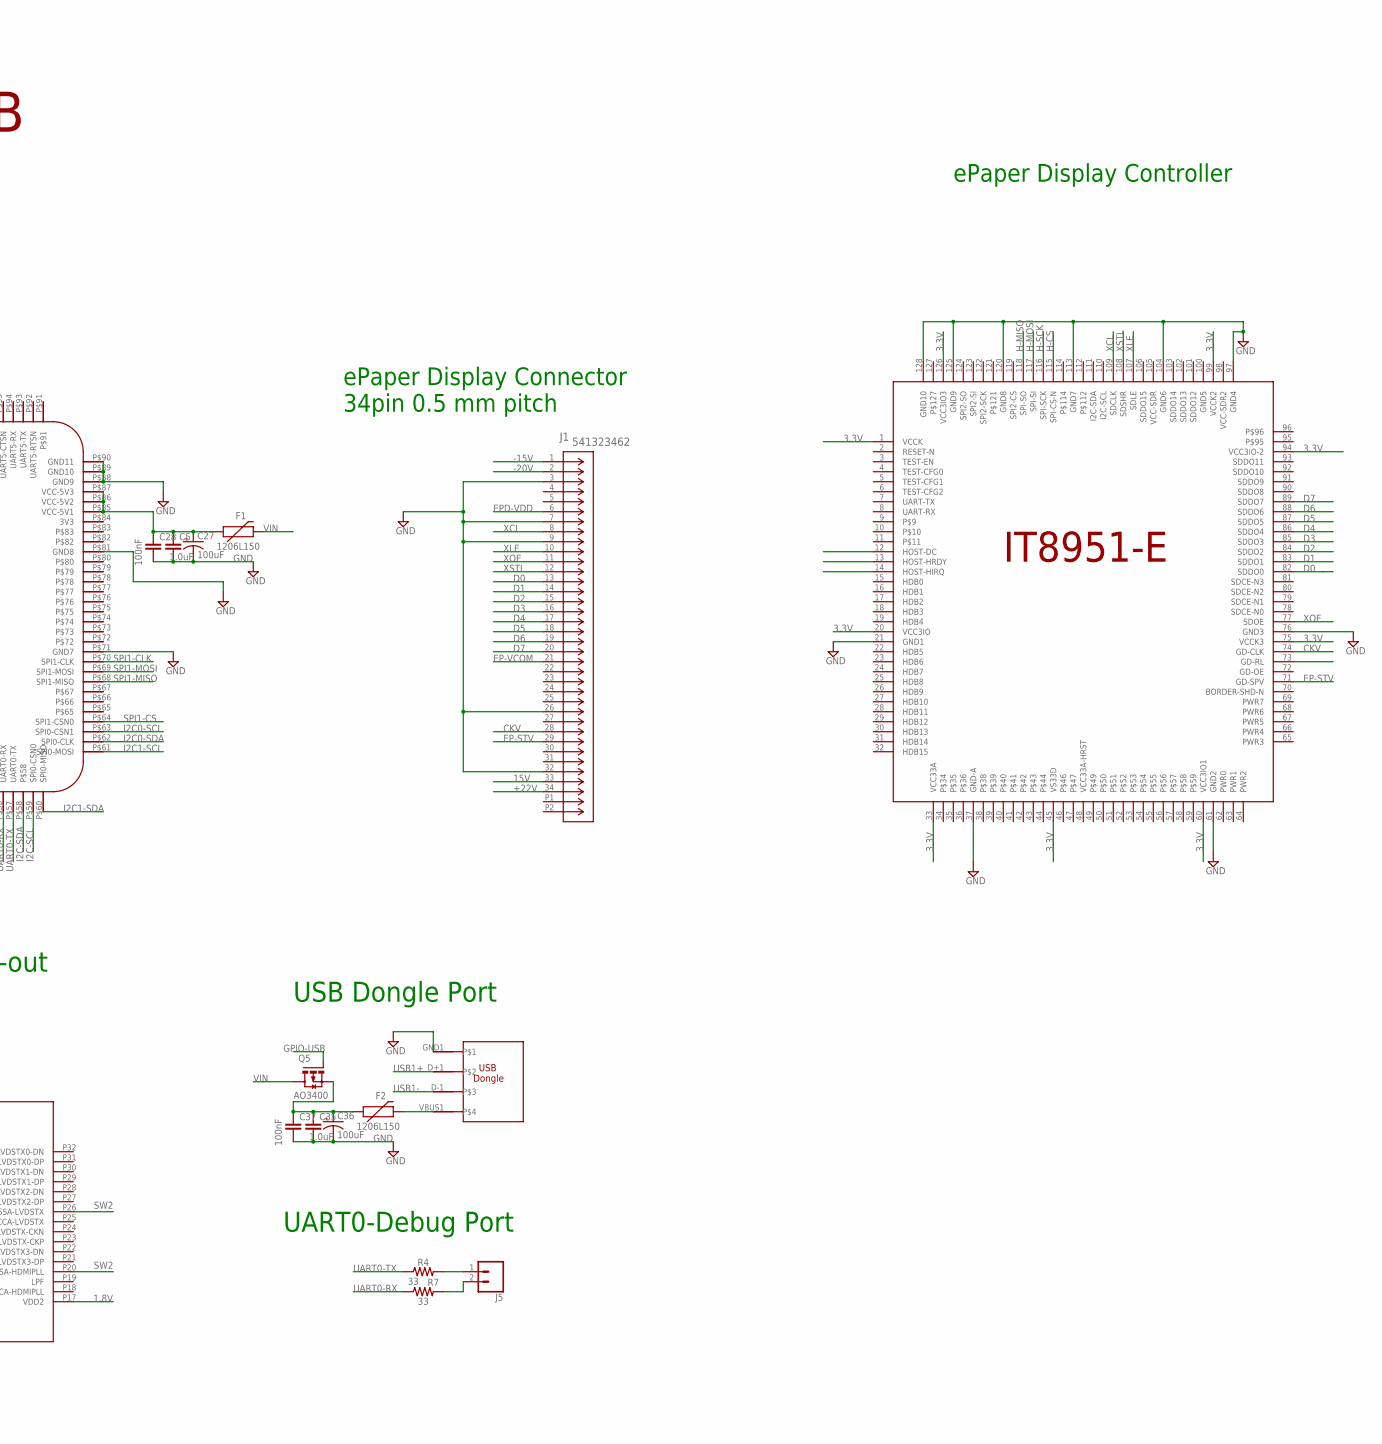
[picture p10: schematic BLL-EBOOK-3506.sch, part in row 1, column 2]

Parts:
C1, C2, C3, C31, C32, C33: 10uF; C0603
C4: 100uF; C0603
C5, C34, C35: 1.0uF; 0603
C6, C7, C8, C13, C14, C15, C16, C24, C25: 4.7uF; 0603
C9, C11, C23, C26: 10uF; 0805
C10, C12: 22uF; 0805
C17, C21: 10nF; 0603
C18, C20: 2.2uF; 1206
C19, C22: 100nF; 0603
C27, C36: 100uF; EIA3528
C28, C37: 100nF; 0805
C29, C30: 22pF; 0603
D1: 1A/40V/500mV; SMA-DIODE
D4, D6, D7, D8, D9, D10: sod323; SOD-323
F1, F2: 1206L150; 1206
FUSE-0603: 500mA; 0603
IC1, IC2: RT9080-33GJ5; SOT94P280X100-5N
IC3: RT9080-18GJ5; SOT94P280X100-5N
J1: 541323462; CON_541323462_MOL
J2: HDMR-19-02-F-SM; SAMTEC_HDMR-19-02-F-SM
J3: DX07S016JA1R1500; JAE_DX07S016JA1R1500
J4: BATT PAD; 1X02/90
J5: CONN_02LOCK; 1X02_LOCK
L1: 4.7μH; 1008(2520)
L2: 2.2μH; 0806
LT8912: LT8912B
Q1: IRLML6402TRPBF; SOT23
Q2: 27Mhz Osc; 5.0X3.2_2
Q3, Q4, Q5: AO3400; SOT23
R1, R2: 5.1k; M0805
R3: 100k; R0603
R4, R7: 33; 0603
R5, R6: 10k; M0805
R8, R9: 4.7k; 0603
R10, R12: 1M; 0603
R11: 53k; 0805
R13: 47.5k; 0805
U2: TPS65185RGZR; QFN50P700X700X100-49N
U3: USBLC6-2P6; SOT50P160X60-6N
U$1: IT8951; LQFP128_STM
U$3: LUCKFOX_CORE3506; CORE3506
U$4: MICROSD-MODULE; MICROSD-MOD
U$5: USB-WIFI-DONGLE; USB-A-SMT-MALE

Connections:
1.8V: C33.1, IC3.5 (VOUT), LT8912.P4 (VCCA-MIPI-RX), LT8912.P17 (VDD2), LT8912.P34 (VDD), LT8912.P42 (VCCA-HDMITX), LT8912.P56 (VDD3)
3.3V: C3.1, IC1.5 (VOUT), R8.2, R9.2, U2.45 (VIN3P3), U$1.1 (VCCK), U$1.20 (VCC3IO), U$1.33 (VCC33A), U$1.45 (VS33D), U$1.60 (VCC3IO1), U$1.75 (VCCK3), U$1.94 (VCC3IO-2), U$1.99 (VCCK2), U$1.126 (VCC3IO3)
3.3V2: C1.1, C32.1, IC2.5 (VOUT), IC3.1 (VIN), IC3.3 (EN), R5.1, R6.1, U$4.P$1 (3V3)
15V: C6.2, J1.33, U2.19 (VPOS_DIS), U2.44 (VPOS)
+22V: C20.1, D8.C, J1.34, R12.2, U2.35 (VDDH_DIS)
-15V: C8.1, J1.1, U2.3 (VNEG), U2.9 (VNEG_DIS)
-20V: C18.2, D7.A, J1.2, R10.1, U2.29 (VEE_DIS)
CKV: J1.28, U$1.74 (GD-CLK)
D0: J1.13, U$1.82 (SDDO0)
D1: J1.14, U$1.83 (SDDO1)
D2: J1.15, U$1.84 (SDDO2)
D3: J1.16, U$1.85 (SDDO3)
D4: J1.17, U$1.86 (SDDO4)
D5: J1.18, U$1.87 (SDDO5)
D6: J1.19, U$1.88 (SDDO6)
D7: J1.20, U$1.89 (SDDO7)
DSI0-DN: LT8912.P1 (MIPI-RX0-DN), U$3.P$7 (DSI-D0N)
DSI0-DP: LT8912.P0 (MIPI-RX0-DP), U$3.P$8 (DSI-D0P)
DSI1-DN: LT8912.P3 (MIPI-RX1-DN), U$3.P$4 (DSI-D1N)
DSI1-DP: LT8912.P2 (MIPI-RX1-DP), U$3.P$5 (DSI-D1P)
DSI-CKN: LT8912.P7 (MIPI-RX-CKN), U$3.P$1 (DSI-CLKN)
DSI-CKP: LT8912.P6 (MIPI-RX-CKP), U$3.P$2 (DSI-CLKP)
EP-STV: J1.29, U$1.71 (GD-SPV)
EP-VCOM: J1.21, U2.15 (VCOM)
EPD-VDD: C26.1, J1.6, U2.46 (V3P3)
GND: C2.2, C3.2, C4.2, C5.2, C6.1, C7.1, C8.2, C9.2, C10.2, C11.2, C12.2, C13.1, C14.1, C15.1, C16.1, C18.1, C19.2, C20.2, C22.1, C23.1, C24.2, C25.2, C26.2, C27.C (-), C28.2, C31.2, C32.2, C34.2, C35.2, C36.C (-), C37.2, IC1.2 (GND), IC2.2 (GND), J1.3, J1.7, J1.9, J1.26, J1.32, J2.02, J2.05, J2.08, J2.11, J2.17, J2.S1 (SHIELD), J2.S2 (SHIELD), J2.S3 (SHIELD), J2.S4 (SHIELD), J3.1 (GND), J3.12 (GND), J3.S1 (SHIELD), J3.S2 (SHIELD), J3.S3 (SHIELD), J3.S4 (SHIELD), J3.S5 (SHIELD), J3.S6 (SHIELD), J4.2, L1.2, Q3.2 (S), Q4.2 (S), R1.2, R2.2, R3.2, R11.2, R13.1, U2.6 (DGND), U2.8 (AGND1), U2.14 (VCOM_DIS), U2.32 (PGND2), U2.41 (PGDN1), U2.48 (AGND2), U3.2 (GND), U$1.21 (GND1), U$1.37 (GND-A), U$1.61 (GND2), U$1.76 (GND3), U$1.97 (GND4), U$1.104 (GND6), U$1.113 (GND7), U$1.120 (GND8), U$1.125 (GND9), U$1.128 (GND10), U$3.P$3 (GND), U$3.P$6 (GND2), U$3.P$9 (GND3), U$3.P$19 (GND4), U$3.P$26 (GND5), U$3.P$47 (GND6), U$3.P$71 (GND7), U$3.P$81 (GND8), U$3.P$88 (GND9), U$3.P$89 (GND10), U$3.P$90 (GND11), U$3.P$100 (GND12), U$3.P$107 (GND13), U$3.P$118 (GND14), U$5.GND1
GPIO-HDMI: Q4.1 (G), U$3.P$28
GPIO-SD: Q3.1 (G), U$3.P$30
GPIO-USB: Q5.1 (G), U$3.P$97
H-CS: U$1.115 (SPI-CS-N), U$3.P$17 (SPI2-CSN)
H-MISO: U$1.118 (SPI-SO), U$3.P$15 (SPI2-MISO)
H-MOSI: U$1.117 (SPI-SI), U$3.P$16 (SPI2-MOSI)
H-SCK: U$1.116 (SPI-SCK), U$3.P$18 (SPI2-CLK)
HDMI-CKN: J2.12, LT8912.P37 (HDMITX-CKN)
HDMI-CKP: J2.10, LT8912.P38 (HDMITX-CKP)
HDMITX0-DN: J2.09, LT8912.P40 (HDMITX0-DN)
HDMITX0-DP: J2.07, LT8912.P41 (HDMITX0-DP)
HDMITX1-DN: J2.06, LT8912.P43 (HDMITX1-DN)
HDMITX1-DP: J2.04, LT8912.P44 (HDMITX1-DP)
HDMITX2-DN: J2.03, LT8912.P46 (HDMITX2-DN)
HDMITX2-DP: J2.01, LT8912.P47 (HDMITX2-DP)
HPD: J2.19, LT8912.P13 (HPD-CBUS)
I2C0-SCL: U$3.P$63 (SPI0-CSN1)
I2C0-SDA: U$3.P$62 (SPI0-CLK)
I2C1-SCL: R8.1, U2.17 (SCL), U$3.P$61 (SPI0-MOSI)
I2C1-SDA: R9.1, U2.18 (SDA), U$3.P$60 (SPI0-MISO)
I2C-SCL: LT8912.P61 (S-SCL), U$3.P$59 (SPI0-CSN0)
I2C-SDA: LT8912.P60 (S-SDA), U$3.P$58
I/O1_1: J3.6 (D+), J3.7 (D+), U3.1 (I/O1_1)
I/O2_1: J3.5 (D-), J3.8 (D-), U3.3 (I/O2_1)
unnamed: C29.2, LT8912.P53 (XTAL0), Q2.1
unnamed: C30.2, LT8912.P52 (XTALI), Q2.2
unnamed: J3.3 (CC1), R2.1
unnamed: J3.9 (CC2), R1.1
unnamed: F2.2, U$5.VBUS1
unnamed: J5.1, R4.2
unnamed: J5.2, R7.2
unnamed: C7.2, U2.1 (VREF)
unnamed: C15.2, U2.4 (VNEG_IN)
unnamed: C14.2, U2.7 (INT_LDO)
unnamed: D4.C, L1.1, U2.25 (VN_SW)
unnamed: C17.1, U2.28 (VEE_DRV)
unnamed: C17.2, D6.A, D7.C
unnamed: C21.1, U2.36 (VDDH_DRV)
unnamed: C34.1, FUSE-0603.1, J2.18
P: C5.1, C27.A (+), C28.1, F1.1, U$3.P$85 (VCC-5V1), U$3.P$86 (VCC-5V2), U$3.P$87 (VCC-5V3)
P1: C35.1, C36.A (+), C37.1, F2.1, Q5.2 (S)
P30: C19.1, D6.C, U2.30 (VEE_D)
P31: R10.2, R11.1, U2.31 (VEE_FB)
P33: R12.1, R13.2, U2.33 (VDDH_FB)
P34: C22.2, D9.A, U2.34 (VDDH_D)
P36: C21.2, D8.A, D9.C
P37: C24.1, C25.1, D10.C, U2.37 (VDDH_IN), U2.42 (VB), U2.43 (VPOS_IN)
P40: D10.A, L2.2, U2.40 (VB_SW)
SPI1-CLK: U$3.P$70 (SPI1-CLK)
SPI1-CS: U$3.P$64 (SPI1-CSN0)
SPI1-MISO: U$3.P$68 (SPI1-MISO)
SPI1-MOSI: U$3.P$69 (SPI1-MOSI)
SPI-CLK: U$3.P$21 (FSPI-CLK), U$4.P$4 (CLK)
SPI-CS: R5.2, U$3.P$20 (FSPI-CSN), U$4.P$2 (CS)
SPI-MISO: R6.2, U$3.P$22 (FSPI-D0), U$4.P$5 (MISO)
SPI-MOSI: U$3.P$23 (FSPI-D1), U$4.P$3 (MOSI)
SW1: Q3.3 (D), U$4.P$6 (GND)
SW2: C1.2, C29.1, C30.1, C33.2, IC3.2 (GND), LT8912.P5 (VSSA-MIPI-RX), LT8912.P16 (VSS2), LT8912.P20 (VSSA-HDMIPLL), LT8912.P26 (VSSA-LVDSTX), LT8912.P33 (VSS), LT8912.P39 (VSSA-HDMITX), LT8912.P45 (VSSA-HDMITX2), LT8912.P50 (VSSA-LVDSPLL), LT8912.P55 (VSS3), Q4.3 (D)
TPS-NINT: U2.2 (/INT)
TPS-PWR-GOOD: U2.23 (PWR_GOOD)
TPS-PWRUP: U2.21 (PWRUP)
TPS-VCOM-CTRL: U2.12 (VCOM_CTRL)
TPS-WAKEUP: U2.5 (WAKEUP)
UART0-RX: R7.1, U$3.P$56 (UART0-RX)
UART0-TX: R4.1, U$3.P$57 (UART0-TX)
USB1+: U$3.P$110 (USB1-DP), U$5.D+1
USB1-: U$3.P$111 (USB1-DN), U$5.D-1
USB+: U3.6 (I/O1_2), U$3.P$108 (USB0-DP)
USB-: U3.4 (I/O2_2), U$3.P$109 (USB0-DN)
VBAT: C4.1, J4.1, Q1.2 (S)
VBUS: D1.A, J3.2 (VBUS), J3.11 (VBUS), Q1.3 (D), R3.1, U3.5 (VBUS)
VIN: C2.1, C9.1, C10.1, C11.1, C12.1, C23.2, C31.1, D1.C, F1.2, FUSE-0603.2, IC1.1 (VIN), IC1.3 (EN), IC2.1 (VIN), IC2.3 (EN), L2.1, Q1.1 (G), Q5.3 (D), U2.10 (VIN), U2.24 (VIN_P)
VNEG-IN: C13.2, C16.2, D4.A, U2.16 (VCOM_PWR), U2.22 (PBKG), U2.26 (VN), U2.27 (VEE_IN)
XCL: J1.8, U$1.109 (SDCLK)
XLE: J1.10, U$1.107 (SDLE)
XOE: J1.11, U$1.77 (SDOE)
XSTL: J1.12, U$1.108 (SDSHR)

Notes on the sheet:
CONEXION USB C
MICRO SD MODULE
PWR 3.3V
battery/usb switching
ePaper Display Power
ePaper Display Connector 34pin 0.5 mm pitch
BLL Ebook Reader Based on Luckfox Core 3506B EPDC IT8951E-64
ePaper Display Controller
DSI-2-HDMI/LVDS-out
PWR SWITCH HDMI-SD MOSFETS-N AO3400
1.8V PWR LT8912B
HDMI Out
USB Dongle Port
UART0-Debug Port

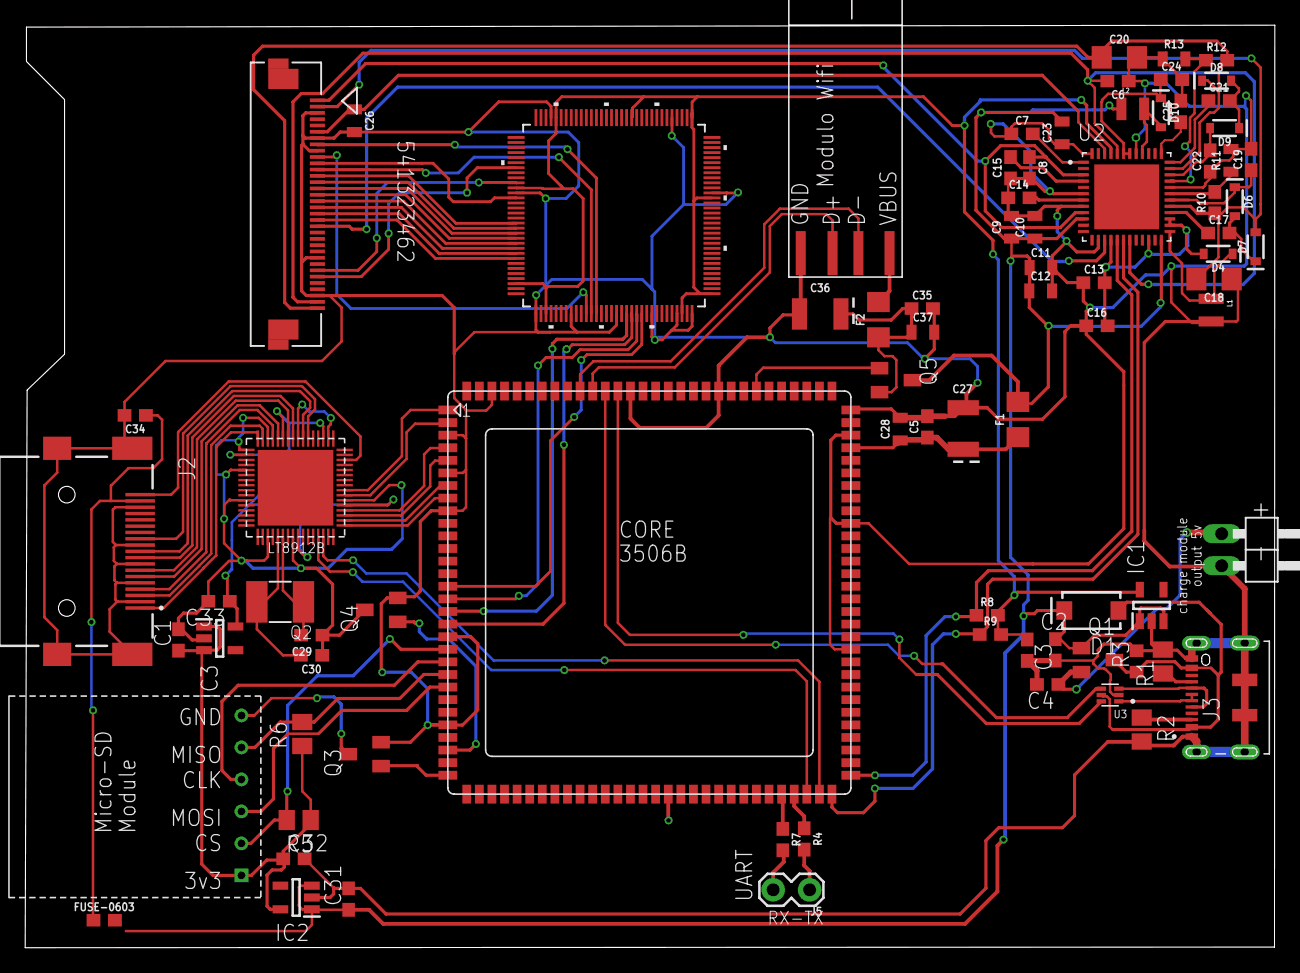
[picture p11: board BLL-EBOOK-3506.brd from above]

Board: 2 copper layers, 99.2 x 73.2 mm, 82 parts (0 on the bottom side), 92 nets.

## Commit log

2025-06-28 UPDATE FILES
    ADD PCB FILES AND EAGLE CUSTOM LIBS
    [BLL-EBOOK.brd, BLL-EBOOK.sch]
2025-06-28 new pcb and sch files
    [BLL-EBOOK.brd, BLL-EBOOK.sch]
2025-06-30 reorganized of repository structure
    [BLL-EBOOK.brd, BLL-EBOOK.sch]
2025-07-04 new bible module
    [rv60 - copia.csv, rv60.csv]
2025-07-05 update rv60 bible text
    [rv60.csv]
2025-07-06 Bibletool updated readme and bible modules
    [rv60.csv]
2025-07-06 instructions for developing and compiling apps
    [rv60.csv]
2025-07-08 complete version of RV60 Bible and tools for validation of files
    [rv60-prueba.csv, rv60.csv]
2025-07-13 Update readme.md
    Bible de log for documentation
2025-07-13 last version of rv60.csv with new text corrections
    deleted duplicated verses, and fixed some verses leng untill Exodus book.
    still need some fixes that will be available as soon as possible.
    - added spanish rv1909 bible (rv09) as a trusted source for local comparison of verses and checking integrity of rv60 spanish bible. also available as a bible version.
    [rv60-prueba.csv]
2025-07-17 new platform build
    [BLL-EBOOK-3506B.brd, BLL-EBOOK-3506B.sch]
2025-07-27 new core design for bll pilot
    [BLL-EBOOK-3506.brd, BLL-EBOOK-3506.sch]
2025-08-04 core 3506B pinout list
    [Core3506.xls]
2025-08-05 new schematic update
    [BLL-EBOOK-3506.brd, BLL-EBOOK-3506.sch]
2025-08-10 new sch and brd design update
    [BLL-EBOOK-3506.brd, BLL-EBOOK-3506.sch]
2025-08-10 updated pcb top
2025-08-12 updated pcb and schematic design
    [BLL-EBOOK-3506.brd, BLL-EBOOK-3506.sch]
2025-08-16 updated pcb and schematic files.
    [BLL-EBOOK-3506.brd, BLL-EBOOK-3506.sch]
2025-09-16 new eagle library added for rpi zero like boards
2025-09-17 new pcb design for new lyra w model
    [BLL-EBOOK-RpiZero.brd, BLL-EBOOK-RpiZero.sch]

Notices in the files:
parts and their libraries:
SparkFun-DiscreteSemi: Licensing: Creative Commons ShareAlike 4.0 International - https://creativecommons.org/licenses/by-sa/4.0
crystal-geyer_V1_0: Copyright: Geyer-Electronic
